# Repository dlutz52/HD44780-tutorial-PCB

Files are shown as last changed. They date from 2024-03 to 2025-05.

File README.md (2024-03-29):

# HD44780 Tutorial PCB

My inspiration for this PCB came from following Ian Ward's project on his web site:

[LCD2004 20×4 LCD Character Display with HD44780 Tutorial](https://excess.org/lcd2004-tutorial/)

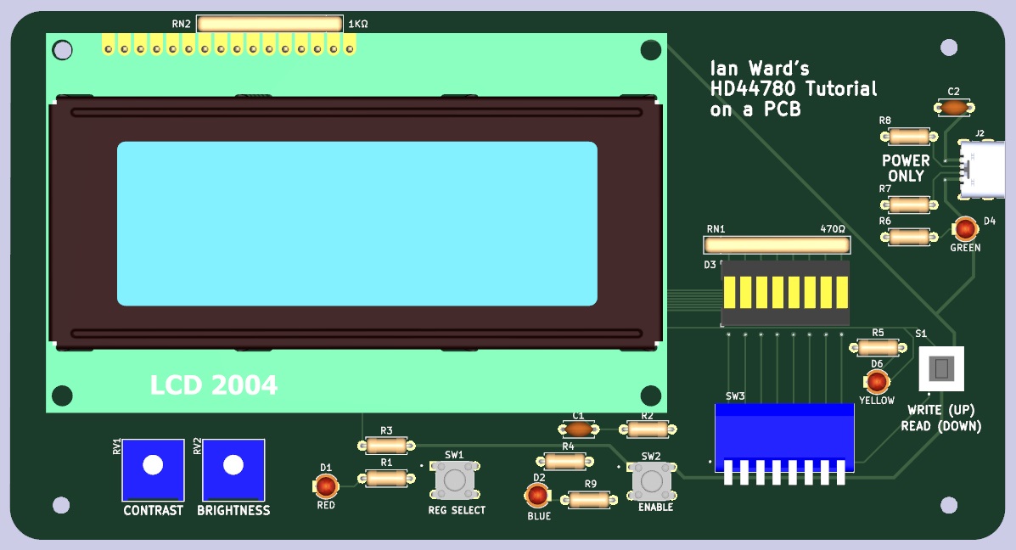
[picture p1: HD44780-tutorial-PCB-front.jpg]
PCB Front Image

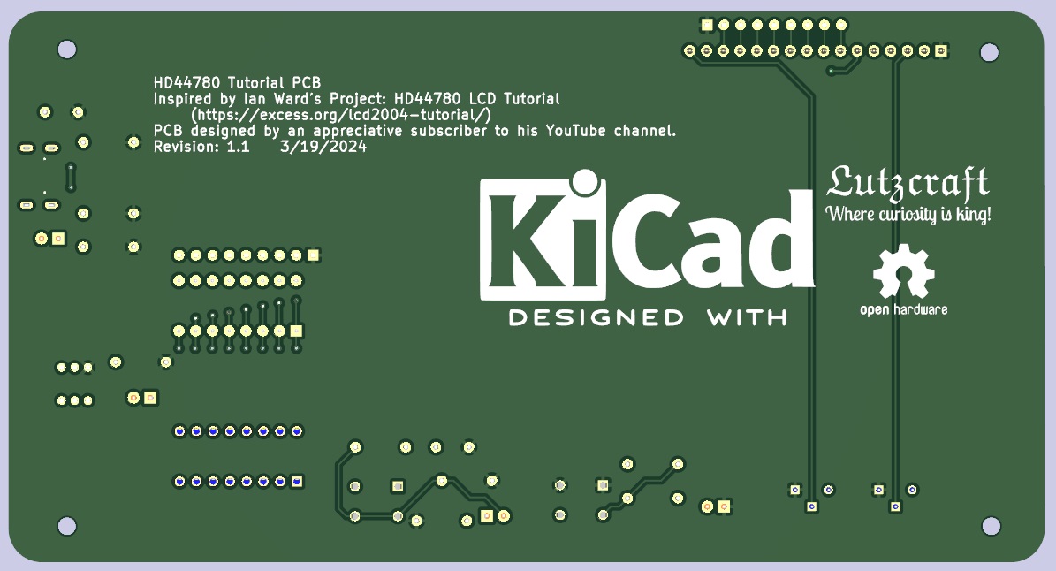
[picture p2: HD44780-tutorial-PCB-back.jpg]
PCB Back Image


# HD44780 Tutorial PCB BOM

## Wed, Mar 20, 2024, 05:20:29

## Component Count: 19

Ref | Qty | Value | Vendor\Part # | Description
----|-----|-------|---------------|-----------
C1, C2 | 2 | .01uF | Digikey\FG28C0G1H103JNT06 | Unpolarized capacitor 
D1 | 1 | RED | Generic | LED\3mm\Red 
D2 | 1 | BLUE | Generic | LED\3mm\Blue 
D3 | 1 | 8_SEG_LED  BAR_GRAPH (RED) | Generic | LED Bar Graph\Red\1x8 
D4 | 1 | GREEN | Generic | LED\3mm\Green 
D5 | 1 | YELLOW | Generic | LED\3mm\Yellow
J1 | 1 | PinSocket_1x16_P2.54mm_Vertical | Generic | Female Pin Header\1x16\2.54mm pitch
J2 | 1 | UJC-HP-M-G-5-MSMT-TR | Digikey\2223-UJC-HP-M-G-5-MSMT-TRDKR-ND | Type C/20 VDC/3A/Horizontal/6 Pin/Power Only
R1, R5, R6, R9 | 4 | 330ohm | Digikey\13-MFR-25FRF52-330RCT-ND | Resistor\330 Ohm\1%\1/4W\Axial
R2, R3, R4 | 3 | 1Kohm | Digikey\13-MFR-25FTE52-1KCT-ND | Resistor\1Kohm\1%\1/4W\Axial
R7, R8 | 2 | 5.1Kohm | Digikey\13-MFR-25FTE52-5K1CT-ND | Resistor\5K1ohm\1%\1/4W\Axial
RN1 | 1 | 470ohm | Digikey\4609X-101-471LF-ND | Resistor Array\ 8 Resistors\470ohm\9SIP
RN2 | 1 | 1Kohm | Digikey\4609X-101-102LF-ND | Resistor Array\ 8 Resistors\1Kohm\9SIP
RV1, RV2 | 2 | 5Kohm | Digikey\3386P-1-502LF | Trimmer Pot\5Kohms\0.5W\1/2W\Through Hole
S1 | 1 | TL2230 | Digikey\EG6031-ND | Switch\Pushbutton\DPDT\Through Hole
SW1 | 1 | REG SELECT | Digikey\450-1654-ND | Switch\Tactile\SPST-NO\0.05A\24V\Through Hole
SW2 | 1 | ENABLE | Digikey\450-1654-ND | Switch\Tactile\SPST-NO\0.05A\24V\Through Hole
SW3 | 1 | DS02C-254-1L-08BE | Digikey\2223-DS02C-254-1L-08BE-ND | Switch\Piano\8-DIP\SPST\25mA\24V\Through Hole

The LCD and its 16-pin male header are represented only with 3D models, but you need a 2004 LCD with a soldered 16-pin male header with a pitch of 2.54mm to plug into the 16 pin female header to complete this PCB. I have found the best place to get these is on eBay.

Do NOT try to use a 2004 LCD with an I<sup>2</sup>C adapter on it.

Most symbols/footprints/models are contained under the 'libraries' directory. Capacitors, resistors and LEDs use KiCad symbols/footprints/models.

KiCad 7.0.10 was used to create this PCB. KiCad 8.0.1 is out now and this project opens in that version. The newer KiCad will warn that this project was created in previous version and will be saved in a the newer format. When closing the schematic or a PCB just discard any changes. If you do not you will not be able to use KiCad 7 any more without difficulties.

Some models in KiCad's 3D view will display an appropriate socket under them but these can be omitted on the PCB - they are used to make it easier to replace any components should they need it in the future.

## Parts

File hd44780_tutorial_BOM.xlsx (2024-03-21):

# | Reference | Qty | Value | Footprint | Vendor\Part # | Vendor URL | Datasheet | Description
1 | C1, C2 | 2 | .01uF | Capacitor_THT:C_Disc_D4.7mm_W2.5mm_P5.00mm | Digikey\445-173474-1-ND | https://www.digikey.com/en/products/detail/tdk-corporation/FG28C0G1H103JNT06/5803088 | https://product.tdk.com/en/system/files | Unpolarized capacitor
2 | D1 | 1 | RED | LED_THT:LED_D3.0mm | Generic |  |  | LED\3mm\Red
3 | D2 | 1 | BLUE | LED_THT:LED_D3.0mm | Generic |  |  | LED\3mm\Blue
4 | D3 | 1 | 8_SEG_LED BAR_GRAPH (RED) | footprints:LED_Bar_Graph_8_SEG_SOCKET | Generic |  |  | LED Bar Graph\Red\1x8
5 | D4 | 1 | GREEN | LED_THT:LED_D3.0mm | Generic |  |  | LED\3mm\Green
6 | D6 | 1 | YELLOW | LED_THT:LED_D3.0mm | Generic |  |  | LED\3mm\Yellow
7 | H1, H2, H3, H4 | 4 | MountingHole | MountingHole:MountingHole_2.7mm_M2.5 | KiCad |  |  | M2.5
8 | J1 | 1 | LCD_2004_PinSocket_1x16_P2.54mm_Vertical | footprints:LCD_2004_PinSocket_1x16_P2.54mm_Vertical | Generic |  |  | Female Pin Header\1x16\2.54mm pitch
9 | J2 | 1 | UJC-HP-M-G-5-MSMT-TR | footprints:CUI_UJC-HP-3-SMT-TR | Digikey\2223-UJC-HP-M-G-5-MSMT-TRDKR-ND | https://www.digikey.com/en/products/detail/cui-devices/UJC-HP-M-G-5-MSMT-TR/16629543 | https://www.cuidevices.com/product/resource/ujc-hp-m-g-5-msmt-tr.pdf | Type C, 20 VDC, 3A, Horizontal, Power Only
10 | R1, R5, R6, R9 | 4 | 330ohm | Resistor_THT:R_Axial_DIN0207_L6.3mm_D2.5mm_P7.62mm_Horizontal | Digikey\13-MFR-25FRF52-330RCT-ND | https://www.digikey.com/en/products/detail/yageo/MFR-25FRF52-330R/9139001 | https://www.yageo.com/upload/media/product/app/datasheet/lr/yageo-mfr_datasheet.pdf | Resistor\330ohm\1%\1/4W\Axial
11 | R2, R3, R4 | 3 | 1Kohm | Resistor_THT:R_Axial_DIN0207_L6.3mm_D2.5mm_P7.62mm_Horizontal | Digikey\13-MFR-25FTE52-1KCT-ND | https://www.digikey.com/en/products/detail/yageo/MFR-25FTE52-1K/9139842 | https://www.yageo.com/upload/media/product/app/datasheet/lr/yageo-mfr_datasheet.pdf | Resistor\1Kohm\1%\1/4W\Axial
12 | R7, R8 | 2 | 5.1Kohm | Resistor_THT:R_Axial_DIN0207_L6.3mm_D2.5mm_P7.62mm_Horizontal | Digikey\13-MFR-25FTE52-5K1CT-ND | https://www.digikey.com/en/products/detail/yageo/MFR-25FTE52-5K1/9140307 | https://www.yageo.com/upload/media/product/app/datasheet/lr/yageo-mfr_datasheet.pdf | Resistor\5K1ohm\1%\1/4W\Axial
13 | RN1 | 1 | 470ohm | footprints:R_Array_SIP9 | Digikey\4609X-101-471LF-ND | https://www.digikey.com/en/products/detail/bourns-inc/4609X-101-471LF/3593678 | https://www.bourns.com/docs/Product-Datasheets/4600x.pdf | Resistor Array\ 8 Resistors\470ohm\9SIP
14 | RN2 | 1 | 1Kohm | footprints:R_Array_SIP9 | Digikey\4609X-101-102LF-ND | https://www.digikey.com/en/products/detail/bourns-inc/4609X-101-102LF/3593658 | https://www.bourns.com/docs/Product-Datasheets/4600x.pdf | Resistor Array\ 8 Resistors\1Kohm\9SIP
15 | RV1, RV2 | 2 | 5Kohm | footprints:BOURNE-3386P | Digikey\3386P-1-502LF | https://www.digikey.com/en/products/detail/bourns-inc/3386P-1-502LF/1088535 | https://www.bourns.com/docs/Product-Datasheets/3386.pdf | Trimmer Pot\5kohms\0.5W\1/2W\Through Hole
16 | S1 | 1 | TL2230 | footprints:TL2230EEF140 | Digikey\EG6031-ND | https://www.digikey.com/en/products/detail/e-switch/TL2230EEF140/4029358 | https://eswitch.wpengine.com/wp-content/uploads/2022/06/TL2201-3.pdf | Switch\Pushbutton\DPDT\Through Hole
17 | SW1 | 1 | REG SELECT | footprints:SW_1825967-1 | Digikey\450-1654-ND | https://www.digikey.com/en/products/detail/te-connectivity-alcoswitch-switches/1825967-1/1632540 | https://www.te.com/usa-en/product-1825967-1.datasheet.pdf | Switch\Tactile\SPST-NO\0.05A\24V\Through Hole
18 | SW2 | 1 | ENABLE | footprints:SW_1825967-1 | Digikey\450-1654-ND | https://www.digikey.com/en/products/detail/te-connectivity-alcoswitch-switches/1825967-1/1632540 | https://www.te.com/usa-en/product-1825967-1.datasheet.pdf | Switch\Tactile\SPST-NO\0.05A\24V\Through Hole
19 | SW3 | 1 | DS02C-254-1L-08BE | footprints:SW_DS02C-254-1L-08BE | Digikey\2223-DS02C-254-1L-08BE-ND | https://www.digikey.com/en/products/detail/cui-devices/DS02C-254-1L-08BE/11310898 | https://www.cuidevices.com/product/resource/ds02-254.pdf | Switch\Piano\8-DIP\SPST\0.025mA\24V\Through Hole

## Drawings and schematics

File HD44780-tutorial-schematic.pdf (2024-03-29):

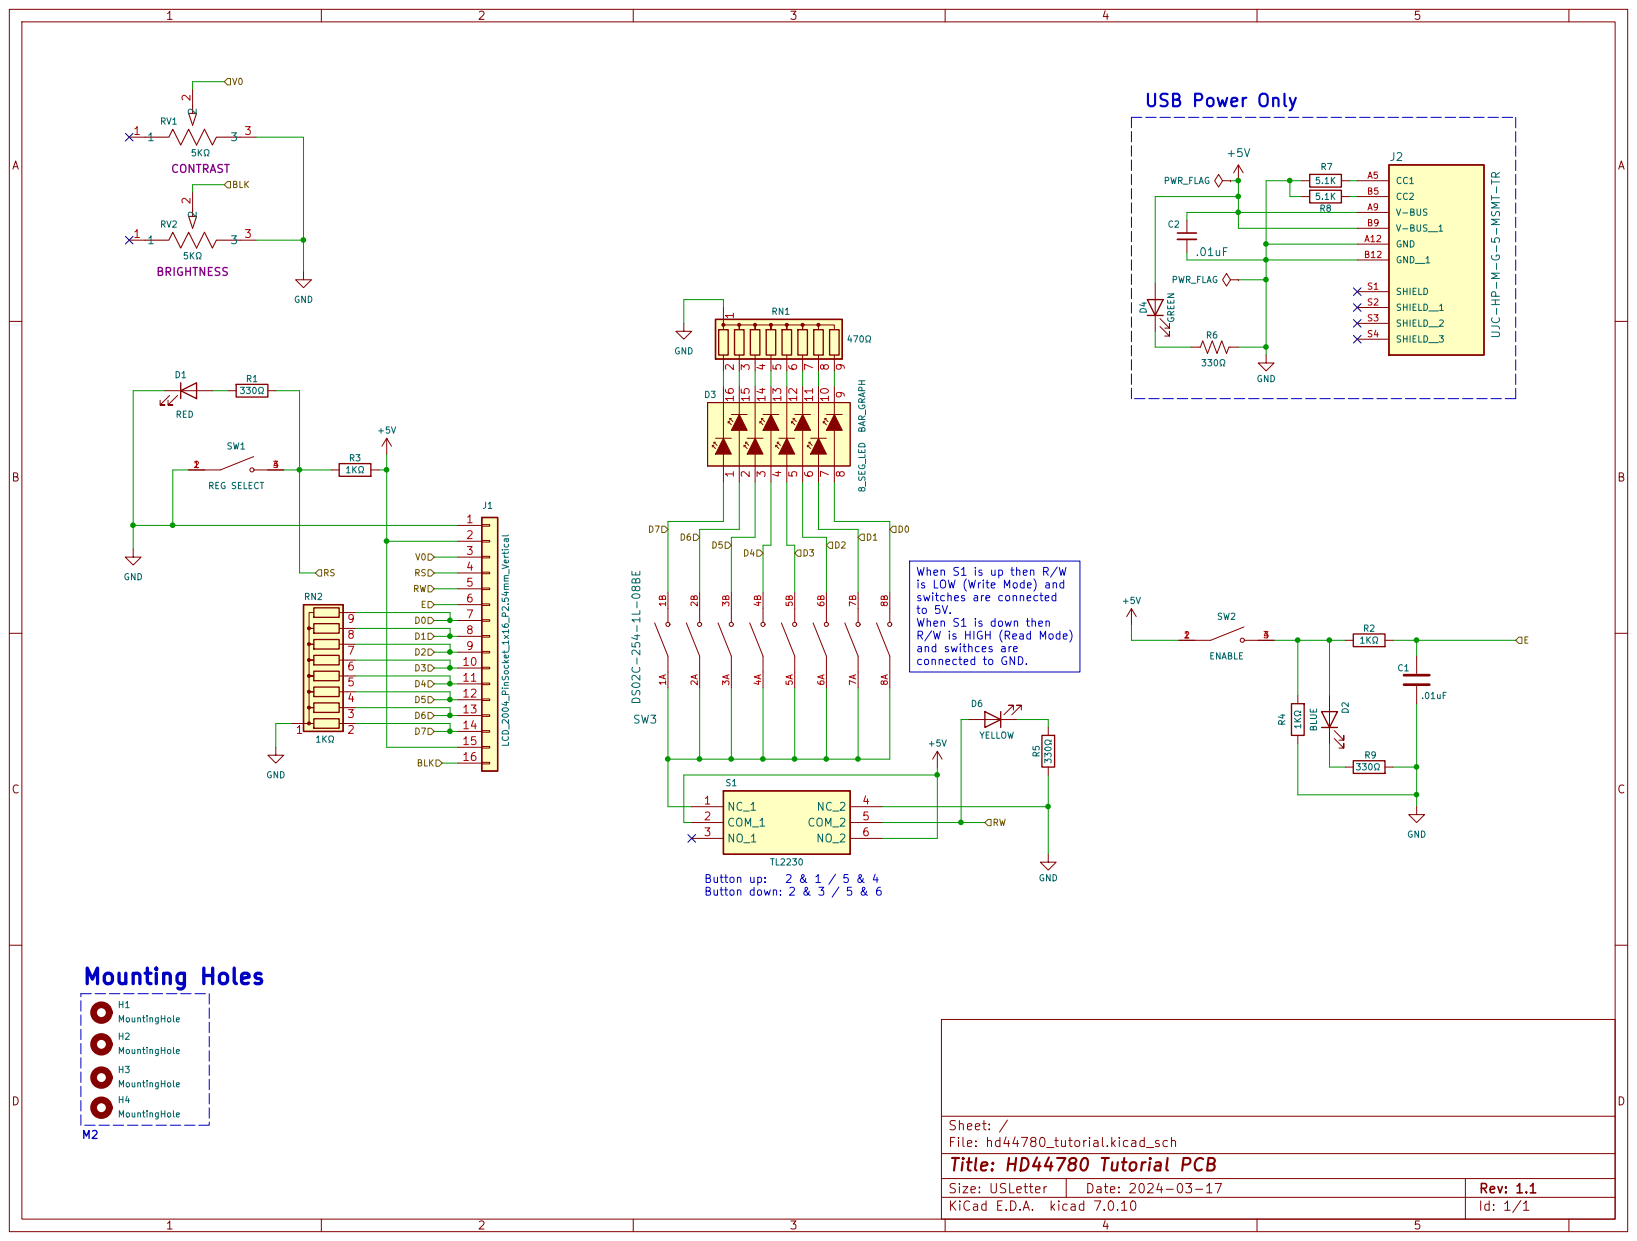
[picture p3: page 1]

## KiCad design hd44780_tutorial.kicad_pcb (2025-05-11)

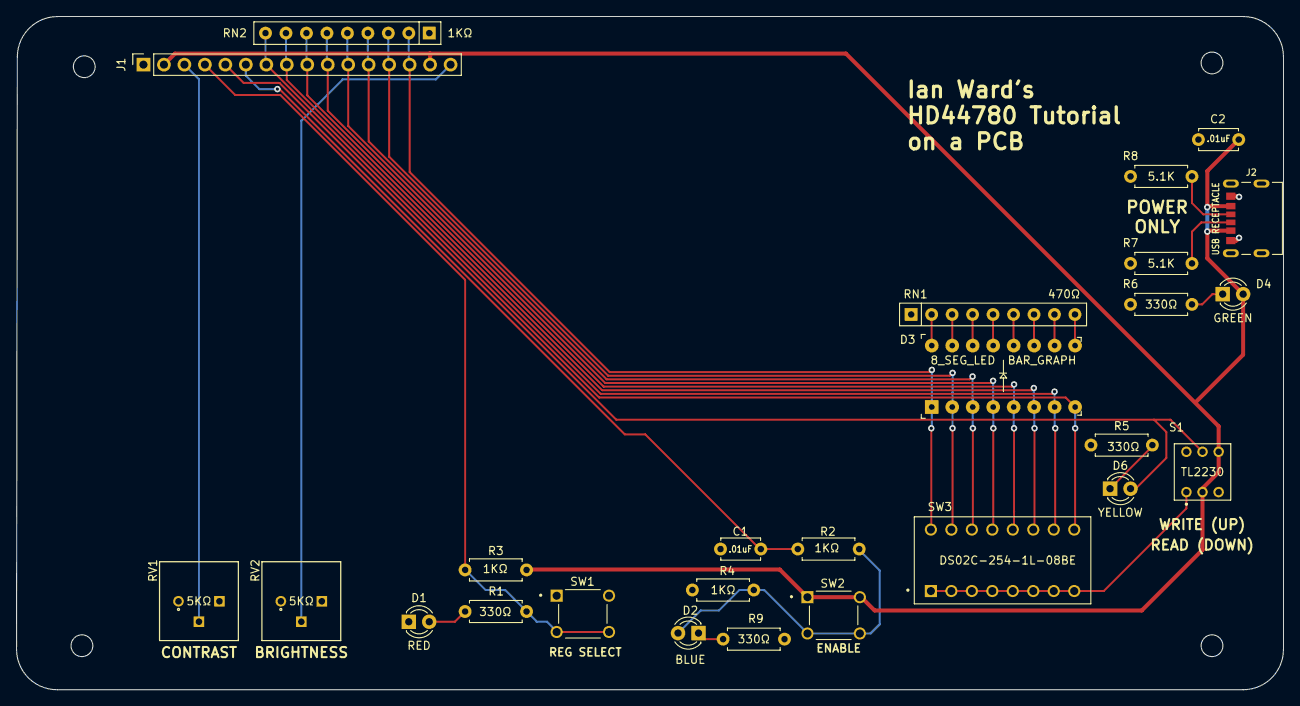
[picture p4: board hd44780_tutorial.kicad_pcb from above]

Board: 2 copper layers, 157.2 x 83.5 mm, 30 parts (0 on the bottom side), 31 nets.

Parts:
C1, C2: .01uF; C_Disc_D4.7mm_W2.5mm_P5.00mm
D1: RED; LED_D3.0mm
D2: BLUE; LED_D3.0mm
D3: 8_SEG_LED BAR_GRAPH; LED_Bar_Graph_8_SEG_SOCKET
D4: GREEN; LED_D3.0mm
D6: YELLOW; LED_D3.0mm
H1, H2, H3, H4: MountingHole; MountingHole_2.7mm_M2.5
J1: LCD_2004_PinSocket_1x16_P2.54mm_Vertical
J2: USB RECEPTACLE; CUI_UJC-HP-M-G-5-MSMT-TR
R1, R5, R6, R9: 330Ω; R_Axial_DIN0207_L6.3mm_D2.5mm_P7.62mm_Horizontal
R2, R3, R4: 1KΩ; R_Axial_DIN0207_L6.3mm_D2.5mm_P7.62mm_Horizontal
R7, R8: 5.1K; R_Axial_DIN0207_L6.3mm_D2.5mm_P7.62mm_Horizontal
RN1: 470Ω; R_Array_SIP9
RN2: 1KΩ; R_Array_SIP9
RV1, RV2: 5KΩ; BOURNE-3386P
S1: TL2230; TL2230EEF140
SW1: REG SELECT; SW_1825967-1
SW2: ENABLE; SW_1825967-1
SW3: DS02C-254-1L-08BE; SW_DS02C-254-1L-08BE

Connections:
+5V: C2.1, D4.2 (A), J1.2, J1.15, J2.A9 (V-BUS), J2.B9 (V-BUS__1), R3.2, S1.2 (COM_1), S1.6 (NO_2), SW2.1, SW2.2
/BLK: J1.16, RV2.2
/D0: D3.8, J1.7, RN2.9 (R8), SW3.8B
/D1: D3.7, J1.8, RN2.8 (R7), SW3.7B
/D2: D3.6, J1.9, RN2.7 (R6), SW3.6B
/D3: D3.5, J1.10, RN2.6 (R5), SW3.5B
/D4: D3.4, J1.11, RN2.5 (R4), SW3.4B
/D5: D3.3, J1.12, RN2.4 (R3), SW3.3B
/D6: D3.2, J1.13, RN2.3 (R2), SW3.2B
/D7: D3.1, J1.14, RN2.2 (R1), SW3.1B
/E: C1.1, J1.6, R2.2
/RS: J1.4, R1.1, R3.1, SW1.3, SW1.4
/RW: D6.2 (A), J1.5, S1.5 (COM_2)
/V0: J1.3, RV1.2
GND: C1.2, C2.2, D1.1 (K), J1.1, J2.A12 (GND), J2.B12 (GND__1), R4.1, R5.1, R6.1, R7.2, R8.2, R9.2, RN1.1 (common), RN2.1 (common), RV1.3, RV2.3, S1.4 (NC_2), SW1.1, SW1.2
unnamed: D1.2 (A), R1.2
unnamed: D2.2 (A), R2.1, R4.2, SW2.3, SW2.4
unnamed: D2.1 (K), R9.1
unnamed: D4.1 (K), R6.2
unnamed: D6.1 (K), R5.2
unnamed: J2.A5 (CC1), R7.1
unnamed: J2.B5 (CC2), R8.1
unnamed: D3.16, RN1.2 (R1)
unnamed: D3.15, RN1.3 (R2)
unnamed: D3.14, RN1.4 (R3)
unnamed: D3.13, RN1.5 (R4)
unnamed: D3.12, RN1.6 (R5)
unnamed: D3.11, RN1.7 (R6)
unnamed: D3.10, RN1.8 (R7)
unnamed: D3.9, RN1.9 (R8)
unnamed: S1.1 (NC_1), SW3.1A, SW3.2A, SW3.3A, SW3.4A, SW3.5A, SW3.6A, SW3.7A, SW3.8A

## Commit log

2024-03-05 Removing gerber ZIP file from repo
2024-03-05 Renamed BOM file
    [hd44780_tutorial_BOM.xlsx]
2024-03-05 Fixed some labels on PCB and made new JPG
    [hd44780_tutorial.kicad_pcb]
2024-03-06 Fixed wiring on the TL2230 switch. Made more space between switches and LEDs. New gerbers and JPEG.
    [hd44780_tutorial-B_Courtyard.gbr, hd44780_tutorial-B_Cu.gbl, hd44780_tutorial-B_Fab.gbr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]
2024-03-07 Final changes to create Version 1.0. Added logo footprints and moved description to back of board. Added title to front of board. Rebuilt gerber/drill files.
    [hd44780_tutorial-B_Courtyard.gbr, hd44780_tutorial-B_Cu.gbl, hd44780_tutorial-B_Fab.gbr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]
2024-03-14 Adjusted some copper tracks. Added Lutzcraft logo to local footprint library.
    [hd44780_tutorial.kicad_pcb]
2024-03-15 Tried a new USB-C port and hate it. Prfeparing to revert to get rid of it.
    [hd44780_tutorial.kicad_pcb, hd44780_tutorial.kicad_sch]
2024-03-15 Revert "Tried a new USB-C port and hate it. Prfeparing to revert to get rid of it."
    This reverts commit 31f363ccd091cdbcf9bc00afb548c8c72483716e.
    [hd44780_tutorial.kicad_pcb, hd44780_tutorial.kicad_sch]
2024-03-15 Adjusted some copper tracks. Made all resistors horizontal. Added 1K network resistor for LCD data lines. Updated version number to 1.0a and date to 3/15/2024.
    [hd44780_tutorial.kicad_pcb, hd44780_tutorial.kicad_sch]
2024-03-17 Determined that adding 1K resistor to SW2 fixes the problem with this board. Created new gerber/drill files.
    [hd44780_tutorial - Copy.kicad_pcb, hd44780_tutorial - Copy.kicad_sch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]
2024-03-17 Brought value of USB connector to front silkscreen.
    [hd44780_tutorial.kicad_pcb]
2024-03-18 Delete hd44780_tutorial - Copy.kicad_pcb
    Never should have been committed
    [hd44780_tutorial - Copy.kicad_pcb]
2024-03-18 Delete hd44780_tutorial - Copy.kicad_sch
    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
    [hd44780_tutorial - Copy.kicad_sch]
2024-03-18 Added *copy.kicad_sch and *copy.kicad_pcb to .gitignore after having deleted two such files online. Minor edits in hd44780_tutorial.kicad_sch
    [hd44780_tutorial.kicad_sch]
2024-03-18 Updated front/back boards images.
2024-03-19 Changed URLs to point to Ian's web site after his suggestion. Moved the RS track so it did not need a via. Regenerated gerber/drill files. Updated front and back images.
    [hd44780_tutorial-B_Courtyard.gbr, hd44780_tutorial-B_Cu.gbl, hd44780_tutorial-B_Fab.gbr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]
2024-03-19 Moved USB connector closer to edge of board.
    [hd44780_tutorial.kicad_pcb]
2024-03-19 Updated gerber/drill files. Updated front image.
    [hd44780_tutorial-B_Courtyard.gbr, hd44780_tutorial-B_Cu.gbl, hd44780_tutorial-B_Fab.gbr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]
2024-03-21 Moved footprint/model for USB-C connector to local library. Updated BOM. Updated images. Regenerated gerber/drill files.
    [hd44780_tutorial-B_Courtyard.gbr, hd44780_tutorial-B_Cu.gbl, hd44780_tutorial-B_Fab.gbr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]
2024-03-21 Another README.md test.
    [hd44780_tutorial_BOM.xlsx]
2024-03-21 Updated XLSX BOM and README.md
    [hd44780_tutorial_BOM.xlsx]
2024-03-21 Change name and value of USB footprint to be correct.
    [hd44780_tutorial-B_Courtyard.gbr, hd44780_tutorial-B_Cu.gbl, hd44780_tutorial-B_Fab.gbr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]
2024-03-21 Updated USB model to match symbol and fooprint.
    [hd44780_tutorial.kicad_pcb]
2024-03-21 Removed mounting holes from BOM.
2024-03-22 Deleted unused Gerbers/hd44780_tutorial-User_Drawings.gbr
    [hd44780_tutorial-User_Drawings.gbr]
2024-03-27 Updated README.md about no I2C adapter on LCD 2004.
2024-03-29 Minor edits to README.md. Added PDF of schematic for non-KiCad users.
2024-10-01 Changed project footprint/symbols directory paths from footprints/hd44780_tutorial to HD44780-tutorial-PCB/HD44780-tutorial-PCB.
    [hd44780_tutorial.kicad_pcb, hd44780_tutorial.kicad_sch]
2024-10-01 Last Kicad v7 version.
    [hd44780_tutorial-B_Courtyard.gbr, hd44780_tutorial-B_Cu.gbl, hd44780_tutorial-B_Fab.gbr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]
2024-10-01 First Kicad v8 version.
    [hd44780_tutorial-B_Courtyard.gbr, hd44780_tutorial-B_Cu.gbl, hd44780_tutorial-B_Fab.gbr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]
2025-05-11 Minor edits
    [hd44780_tutorial.kicad_pcb]
